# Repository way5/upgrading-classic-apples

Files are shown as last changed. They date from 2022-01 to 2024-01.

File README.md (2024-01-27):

# <p align="center">Upgrading Classic Apples</p>

<p align="center">
Apple Logo
</p>

<h2>Table of Contents</h2>

+ [**- Macintosh Classic**](#--macintosh-classic)
+ [**- Macintosh Plus**](#--macintosh-plus)
+ [**- Zero Track Finder for SONY MP-F75W**](#--zero-track-finder-for-sony-mp-f75w)
+ [**- Apple II / II+**](#--apple-ii--ii)
  + [**+ DATANEKTICS Keyboard: key switch shackle**](#-datanektics-keyboard-key-switch-shackle)
  + [**+ Rear Insert for Apple II**](#-rear-insert-for-apple-ii)
+ [**- Apple Keyboard (M7803)**](#--apple-keyboard-m7803)
+ [**- Apple Silentype (A2M0032)**](#--apple-silentype-a2m0032)

<br>

<table cellpadding="0" cellspacing="0" width="100%">
<tr><td>

ATTENTION

</td><td>

**<u>DISCHARGE</u> the CRT before doing any service inside of your Mac.**

</td></tr>

<tr><td>



</td><td>

**Please refer to [issues](https://github.com/way5/mac-classic-pram-battery-bay/issues) :beetle: if you have a suggestion or found an error.**&nbsp;&nbsp;&nbsp;&nbsp;&nbsp;&nbsp;&nbsp;&nbsp;&nbsp;&nbsp;&nbsp;&nbsp;&nbsp;&nbsp;&nbsp;&nbsp;&nbsp;&nbsp;&nbsp;&nbsp;&nbsp;&nbsp;&nbsp;&nbsp;&nbsp;&nbsp;&nbsp;&nbsp;&nbsp;&nbsp;&nbsp;&nbsp;&nbsp;&nbsp;&nbsp;&nbsp;&nbsp;&nbsp;&nbsp;&nbsp;&nbsp;&nbsp;&nbsp;&nbsp;&nbsp;&nbsp;&nbsp;&nbsp;&nbsp;&nbsp;&nbsp;&nbsp;&nbsp;

</td></tr>
</table>

## **- [Macintosh Classic](./models/macintosh%20classic/)**

<table cellpadding="0" cellspacing="0" width="100%">
<tr><td width="160px">
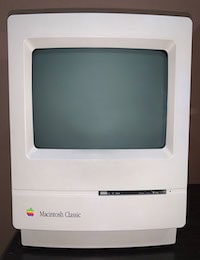
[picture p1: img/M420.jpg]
Macintosh Classic

</td><td>
The PRAM battery compartment sits between the logic board and the case (see photos).<br>Batteries will serve longer if you choose to use it from the same manufaturer and maintain them well charged. In my experience 3.2-3.9V total is enougn for proper timekeeping.
</td></tr></table>

<br>

**BOM:**

1. PRAM battery compartment
   - Wire <= AWG22 ~ 0.1 m
   - Single flat contact plates for AA, AAA batteries - 6 pcs.

---

**PLEASE NOTE**: \
Before to install the battery compartment with the batteries inside it should be electrically isolated from the logic board, otherwise the permanent damage of electrical circuits might occur. For that purpose I'm using thin (~0.5mm) transparent film, wrapping it over the battery compartment and securing it on the connector (see photos).

---

**<h3>+ Photos</h3>**

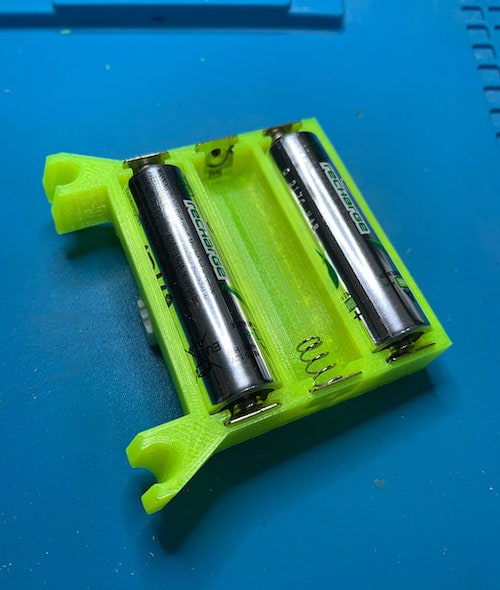
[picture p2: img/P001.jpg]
top view
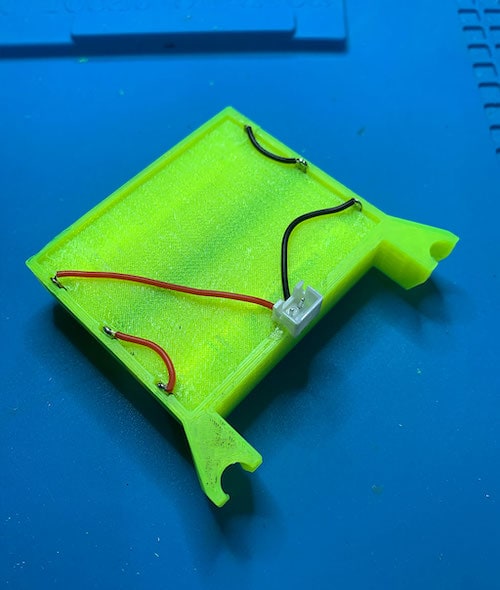
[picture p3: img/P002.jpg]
bottom view
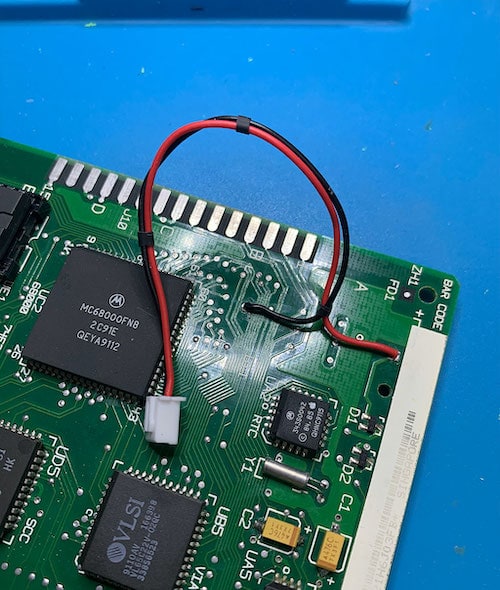
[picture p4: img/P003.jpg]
logic board
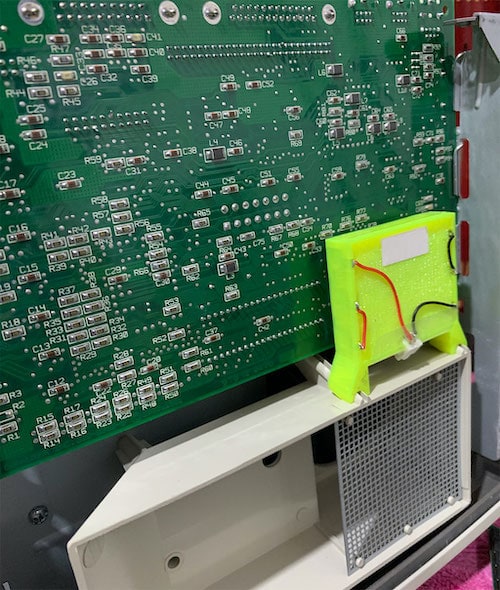
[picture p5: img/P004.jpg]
installation
|  |  |  |  |
|:---:|:---:|:---:|:---:|

</br>

## **- [Macintosh Plus](./models/macintosh%20plus/)**

<table cellpadding="0" cellspacing="0" width="100%">
<tr><td width="160px">
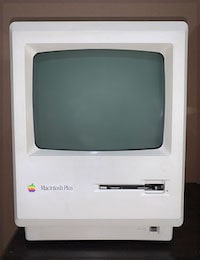
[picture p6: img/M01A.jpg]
Macintosh Plus

</td><td>

PRAM Battery. <br>The battery case is pretty much as for previous model with the only difference, it attaches directly to standard battery holder of Mac. Despite it designed to use 4.5V battery, in my experience 3.5 ± 0.4V is enough.  <br>Cooling Fan (Noninvasive method). <br>Mac Plus was designed to be cooled passively via natural convective flow through the ventilation grates all over its housing. Usually this is not enough, so it gets noticeably hot, so the cooling fan may be installed in order to make Mac's life longer.

</td></tr></table>

<br>

**BOM:**

1. PRAM battery compartment
   - Wire <= AWG22 ~ 0.1m
   - Single flat contact plates for AA, AAA batteries - 6 pcs.
   - Copper foil ~ 30mm2

**<h3>+ Photos</h3>**

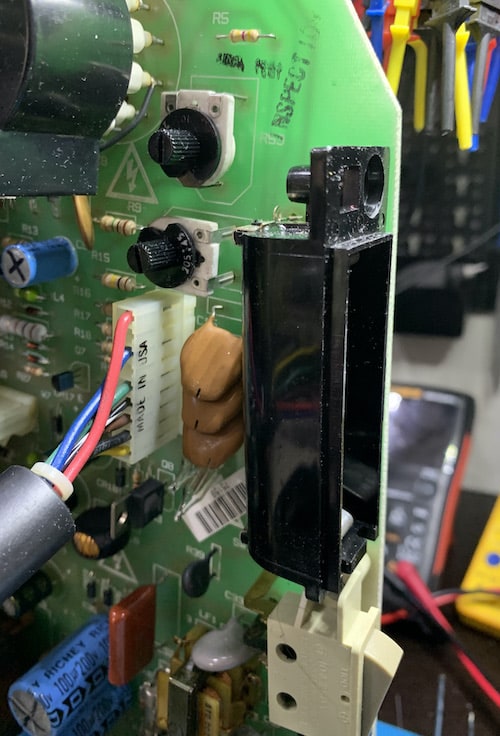
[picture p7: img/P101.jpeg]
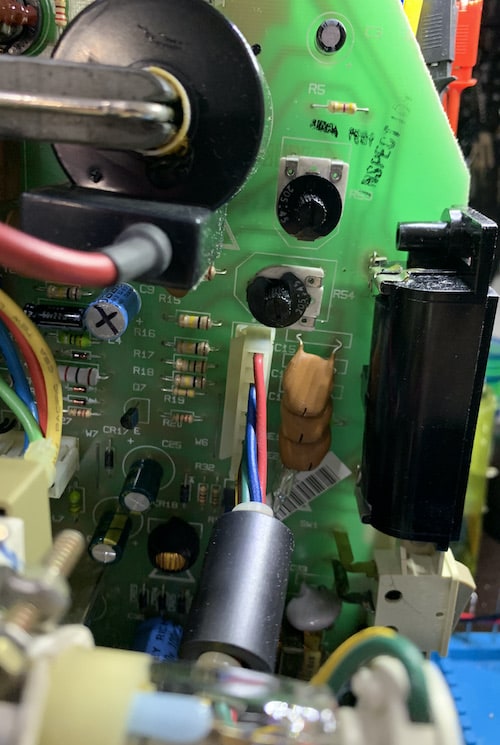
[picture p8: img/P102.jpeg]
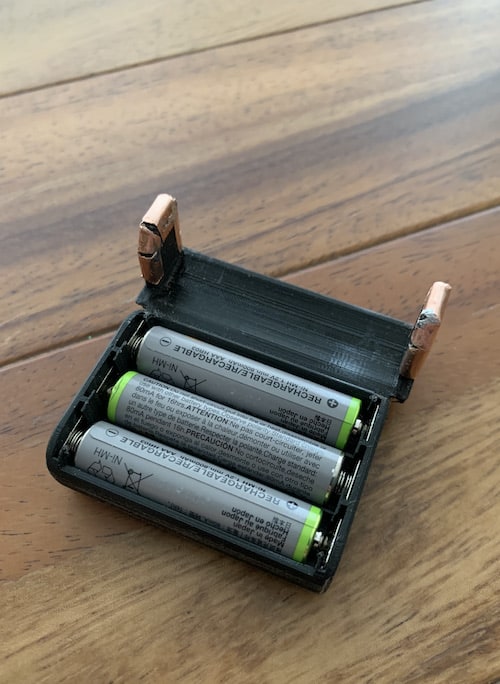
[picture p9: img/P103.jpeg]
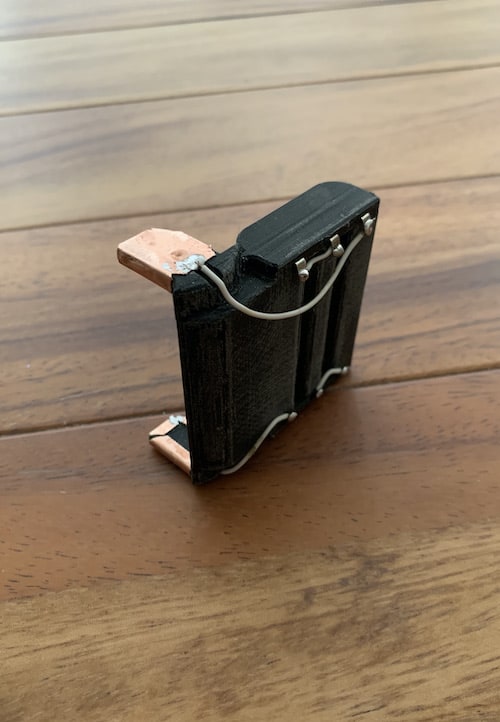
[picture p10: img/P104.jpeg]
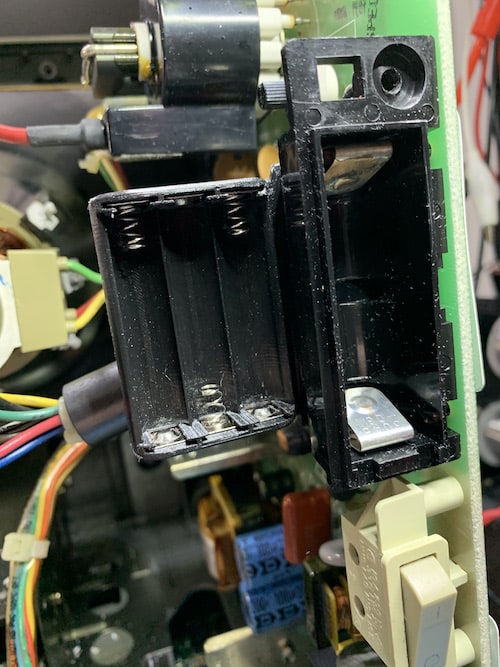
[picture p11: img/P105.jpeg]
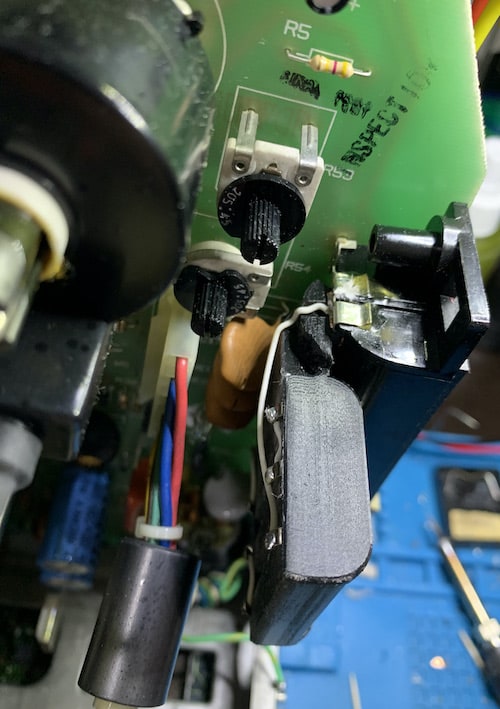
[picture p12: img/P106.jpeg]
|  |  |  |  |  |  |
|:---:|:---:|:---:|:---:|:---:|:---:|

<br>

2. Cooling fan
   - Bolts M3 - 4 pcs.
   - Thru Threaded Inserts M3 - 4 pcs.
   - Washer Head Screws (for plastic) - 2 pcs.
   - Wire <= AWG22 - 0.5m
   - Diode rectifier (ex. 1N4007) - 1 pcs.
   - Double sided tape.
<br>Optional:
   - Copper foil ~ 30mm2
   - Resistor (~50Ω) - 1 pcs.

<br>

---

**PLEASE NOTE:**: \
I'd not recommend you to use the fancy connector that you can see on the photos below, unless you know what you are doing. It requires that its both parts to be perfectly aligned, so when you close the housing it makes secure contact at all times.<br>
A much secure solution is to use any of the following connectors:

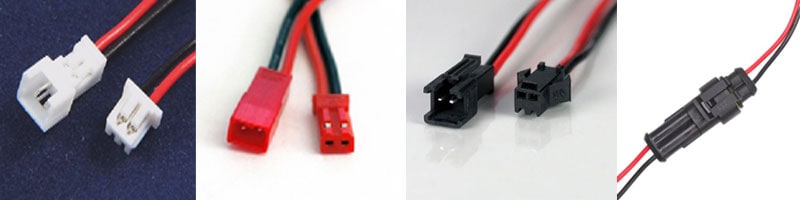
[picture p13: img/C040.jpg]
connectors


---

**<h3>+ Photos</h3>**

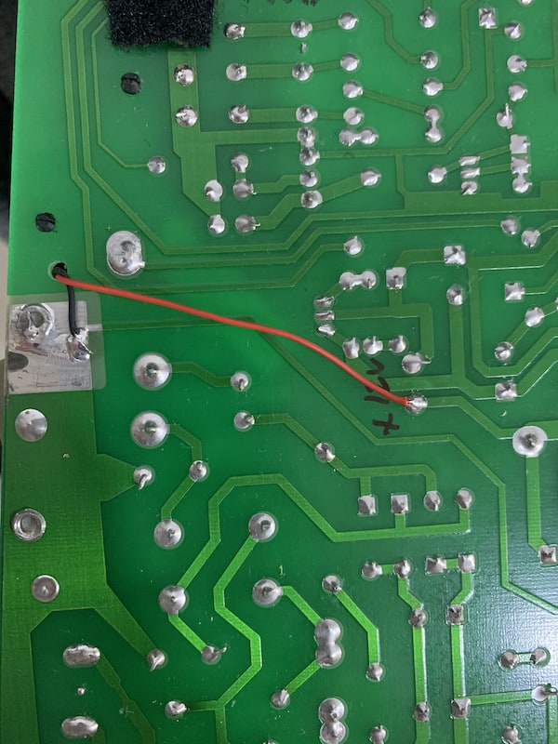
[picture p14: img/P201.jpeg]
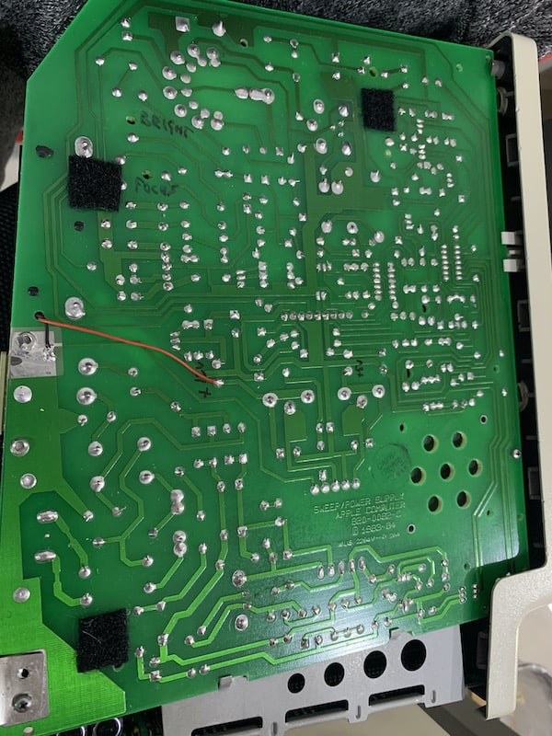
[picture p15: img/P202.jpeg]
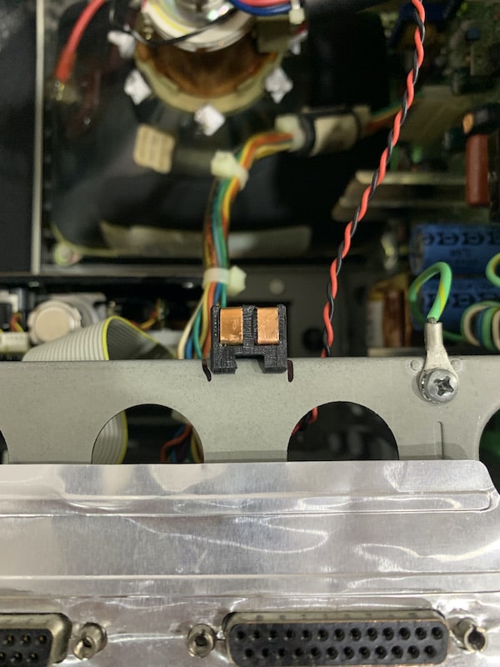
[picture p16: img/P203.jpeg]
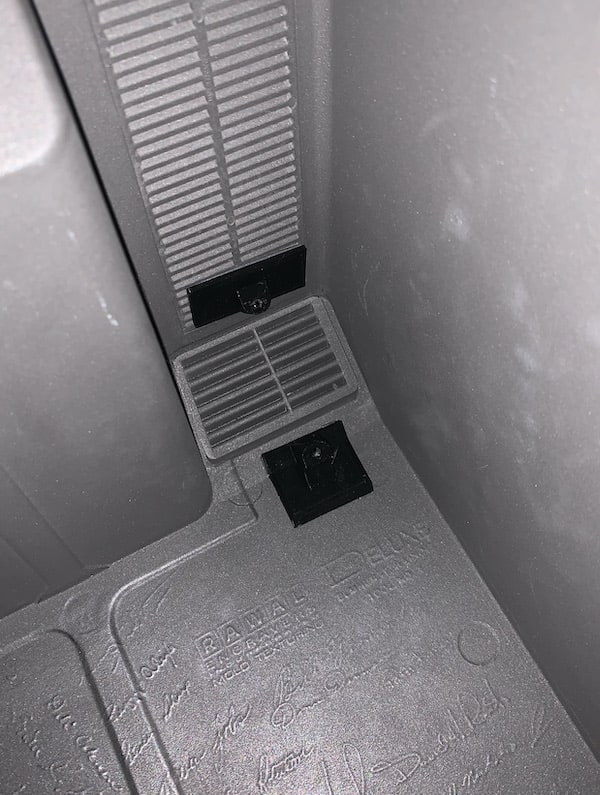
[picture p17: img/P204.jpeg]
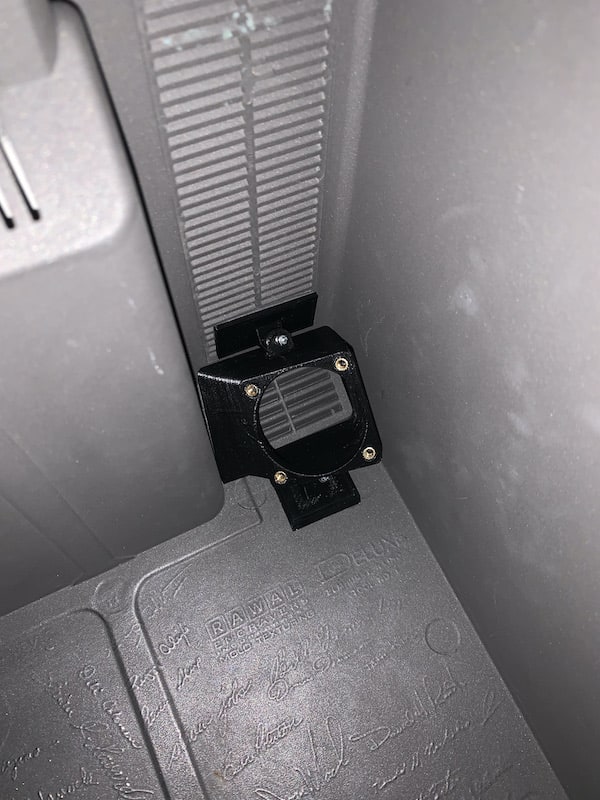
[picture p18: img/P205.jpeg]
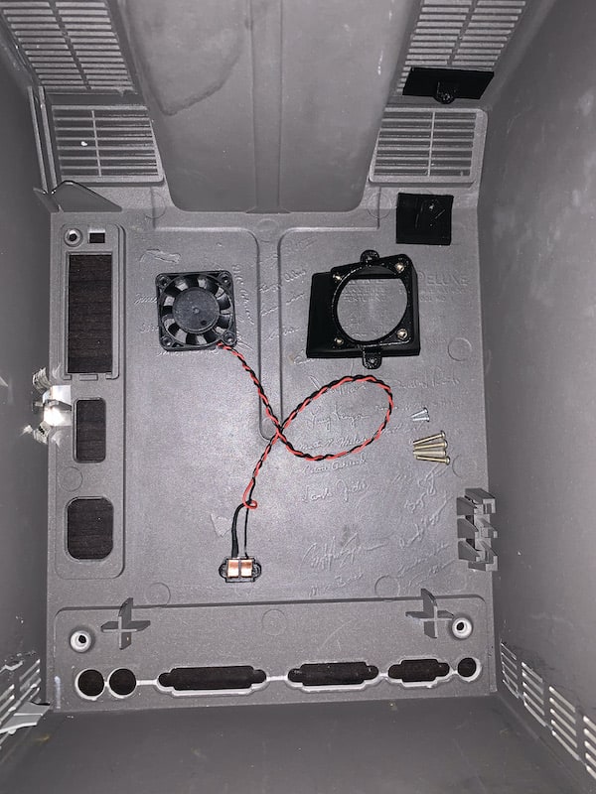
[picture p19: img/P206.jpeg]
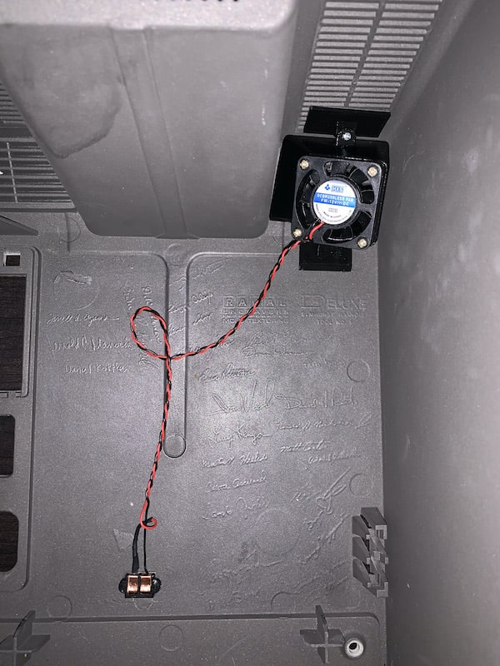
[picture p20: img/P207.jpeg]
|  |  |  |  |  |  |  |
|:---:|:---:|:---:|:---:|:---:|:---:|:---:|

<br>

## **- [Zero Track Finder for SONY MP-F75W](./models/sony%20MP-F75W/)**

<table cellpadding="0" cellspacing="0" width="100%">
<tr><td width="160px">
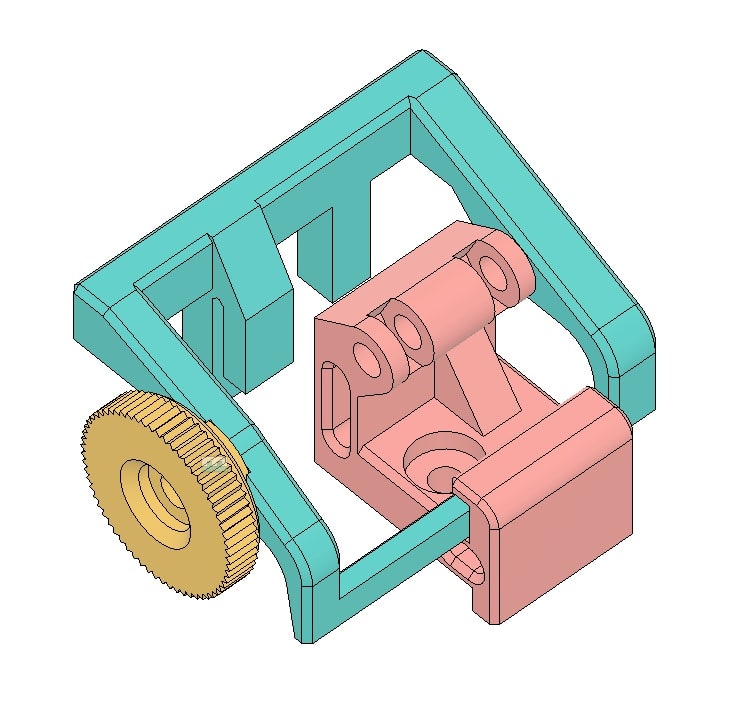
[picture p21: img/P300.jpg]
Zero Track finder for SONY-F75W

</td><td>

**<p>DO NOT USE if your drive operates properly</p>**
A simple tool which may help you to adjust zero track sensor on SONY-F75W-XX floppy drives. Place it over the sensor and secure the assembly. Loosen the sensor screw and slowly adjust the knob, insert the disk. If zero track has been found the floppy will start reading properly, if not repeat adjustment and insert the disk again. Once you finished, secure the sensor on its place and take off Zero Finder assembly.

</td></tr></table>

**<h3>+ Photos</h3>**

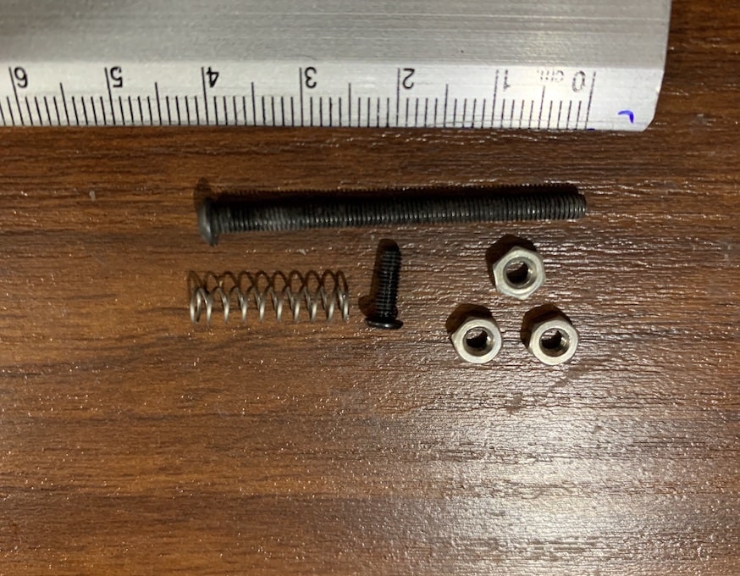
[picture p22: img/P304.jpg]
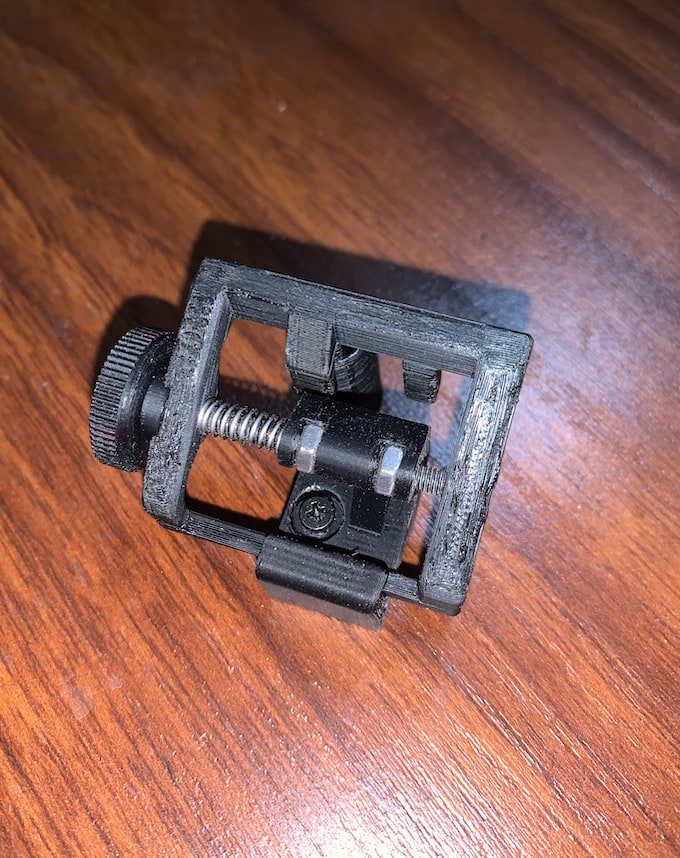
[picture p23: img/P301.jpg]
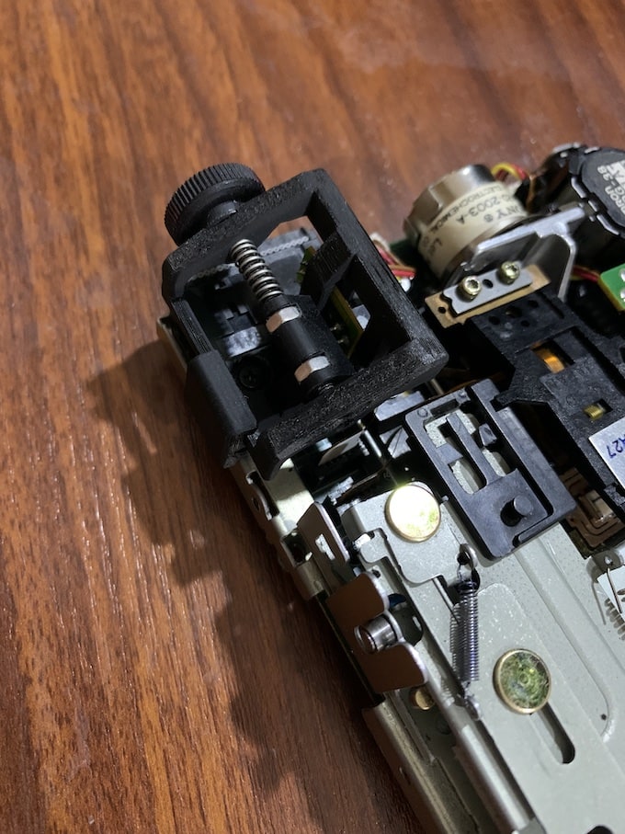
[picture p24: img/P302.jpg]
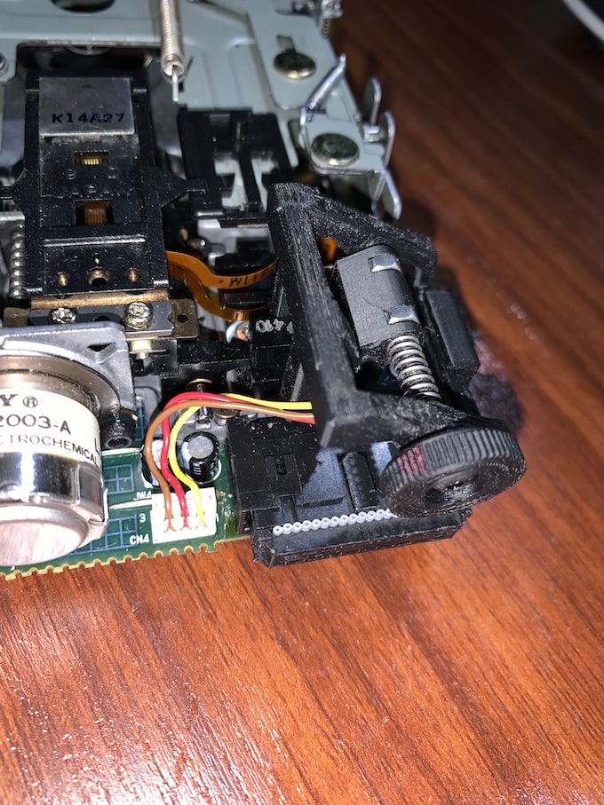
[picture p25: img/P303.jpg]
|  |  |  |  |
|:---:|:---:|:---:|:---:|
<br>

## **- [Apple II / II+](./models/apple%20II/)**

### **+ [DATANEKTICS Keyboard: key switch shackle](./models/apple%20II/datanectics%20keyboard%20switch%20shackle_v7.f3d)**

<table cellpadding="0" cellspacing="0" width="100%">
<tr><td width="160px">

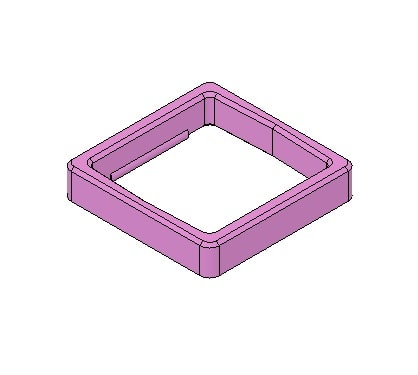
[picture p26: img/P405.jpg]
Apple II Datanekticts Keyboard repair


</td><td>

There are a multiple ways to repair Apple II's Datanektiks keyboard. My decision was to crack open all malfunctioning key switches to give them a proper maintainment. When the key is back to work, clean and lubricated, you may glue the both halves of the key mechanism together as it was before or to leave the opportunity to painlessly open if it will fail again. The key swith shackle securely holds the both parts of the mechanism together and may be easily removed by whatever reason you need to open the switch in future. 
<p><u>Hint:</u> Be very careful when opening the key switch with the cutter knife, do not apply too much force. Open it from the opposite side to the contact pins.</p>

</td></tr></table>

**<h3>+ Photos</h3>**

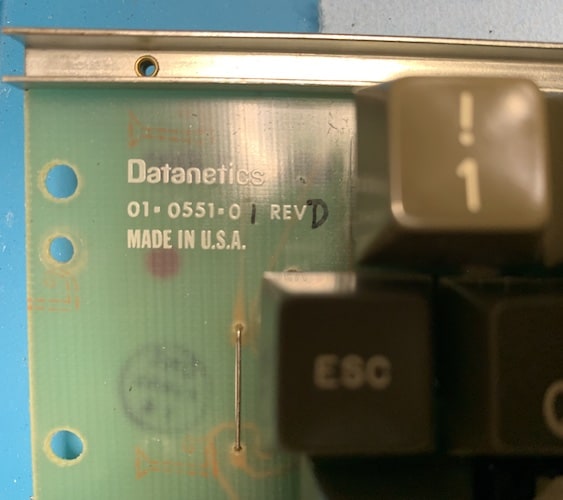
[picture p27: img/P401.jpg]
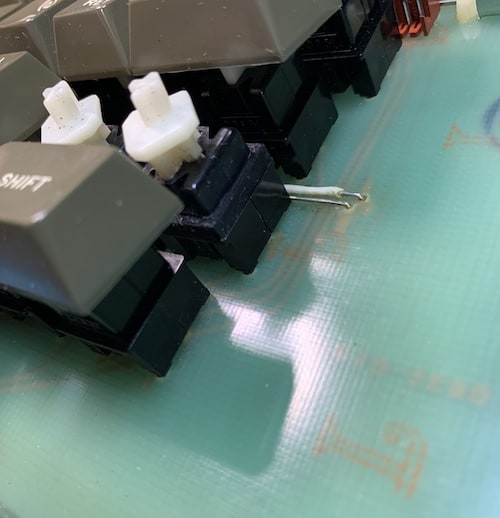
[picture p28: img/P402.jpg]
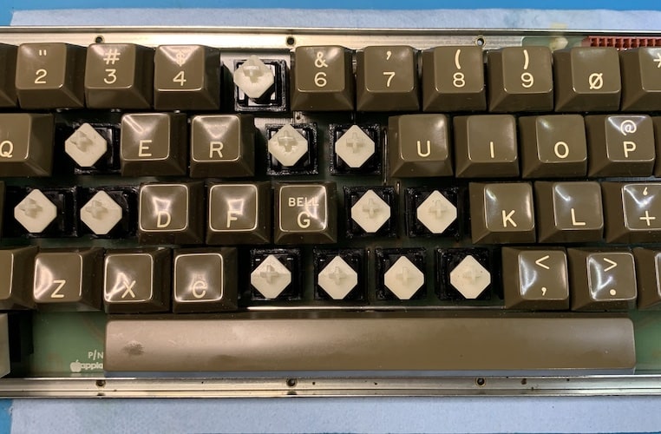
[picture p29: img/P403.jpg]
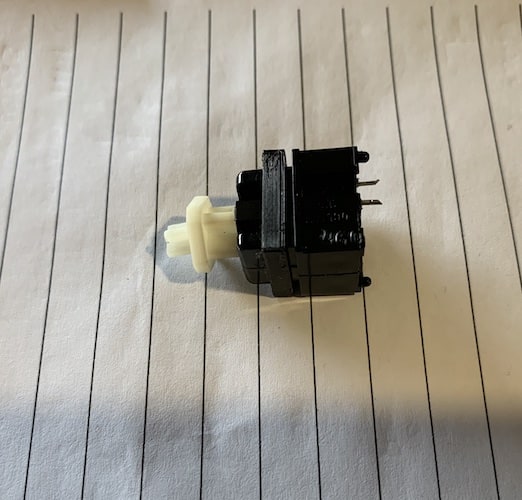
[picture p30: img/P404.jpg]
|  |  |  |  |
|:---:|:---:|:---:|:---:|

### **+ [Rear Insert for Apple II](./models/apple%20II/rear_insert_v16.f3d)**
<table cellpadding="0" cellspacing="0" width="100%">
<tr><td width="160px">
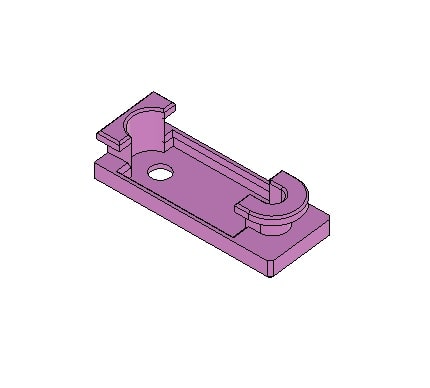
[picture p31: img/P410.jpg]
Apple II Plus

</td><td>

Just a simple insert, originally designed for Apple II+ in order to allow some cable management on the rear side of the housing.

</td></tr></table>

<br>

## **- [Apple Keyboard (M7803)](./models/imac%20g4/m7809_keyboard_key_shaft.stl)**

<table cellpadding="0" cellspacing="0" width="100%">
<tr><td width="160px">
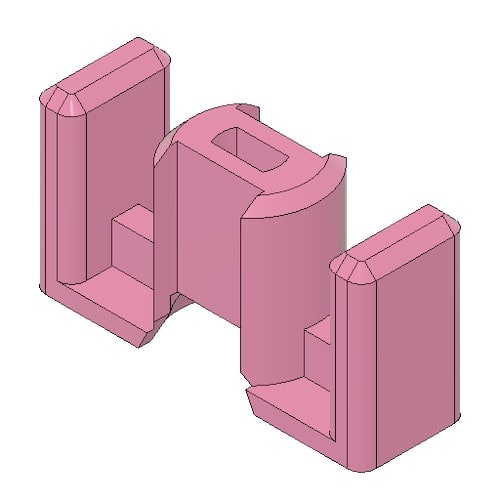
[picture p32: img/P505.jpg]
iMac G4 keyboard M7803

</td><td>

The Apple keyboards are rarely reliable particularly an old ones. Let's give a chance to one of the most fragile devices by modifying the switching mechanism, adding custom key shaft instead of an unreliable side clips.

</td></tr></table>

**<h3>+ Photos</h3>**

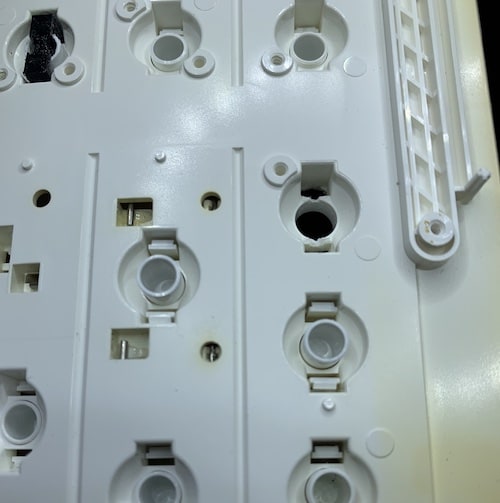
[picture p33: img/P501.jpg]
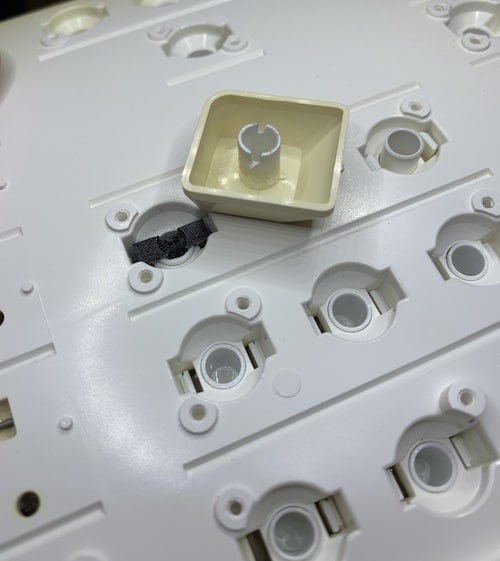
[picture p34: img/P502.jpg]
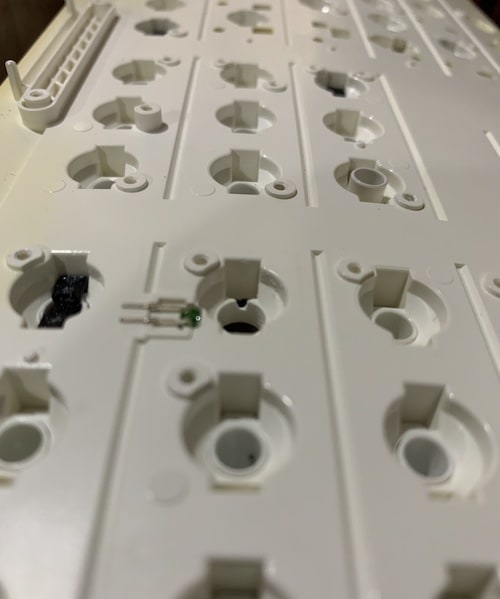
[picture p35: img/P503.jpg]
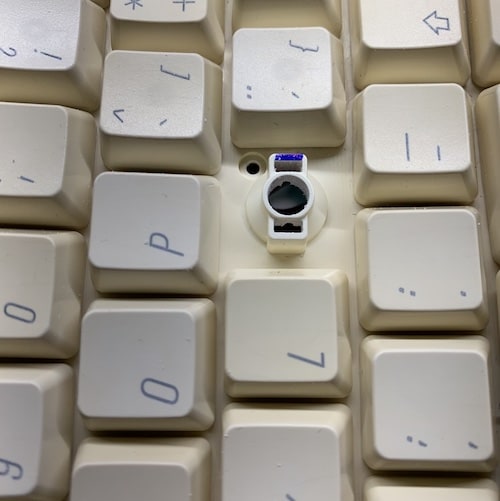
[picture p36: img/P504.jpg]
|  |  |  |  |
|:---:|:---:|:---:|:---:|

## **- [Apple Silentype (A2M0032)](./models/apple%20silentype/)**

<table cellpadding="0" cellspacing="0" width="100%">
<tr><td width="160px">
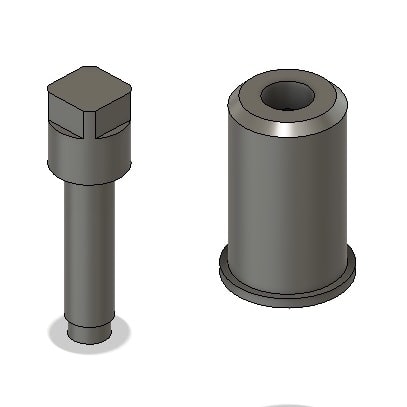
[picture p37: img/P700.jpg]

</td><td>

The Apple Silentype had two plastic inserts on both sides of the paper roll. Sometimes one or both of these are lost. To fully assemble the insert you'd also need a spiral spring of corresponding diameters and the starlock stopper ring (outer d = ~7mm).

</td></tr>
<tr><td width="160px">
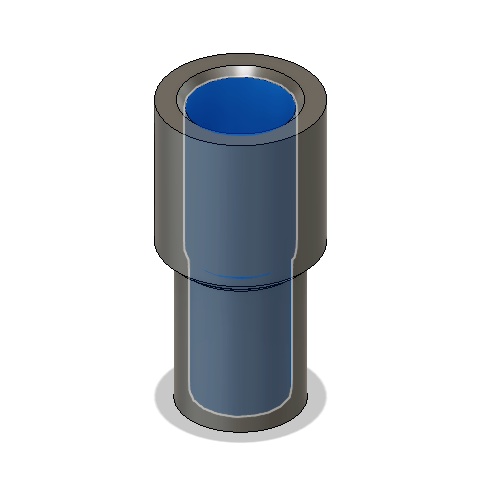
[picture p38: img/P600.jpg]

</td><td>

The main shaft of paper feeding mechanism is connected to the stepper motor through the plastic bushing which becomes brittle over time. You probably already faced the need to replace it or in the near future would do. This [printable model](./models/apple%20silentype/bushing.stl) may resolve the issue.

</td></tr></table>

**<h3>+ Photos</h3>**

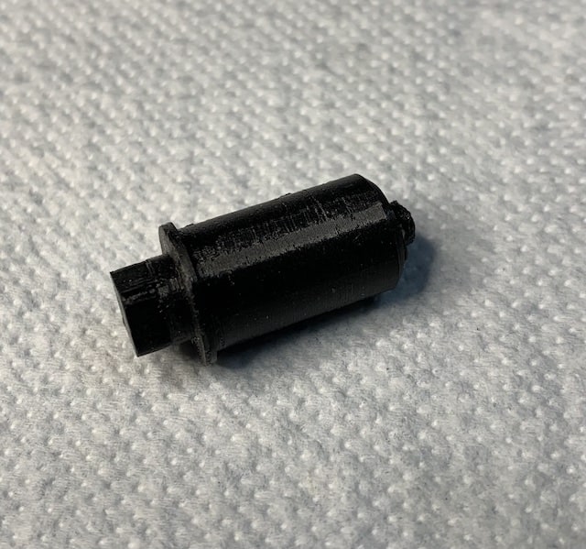
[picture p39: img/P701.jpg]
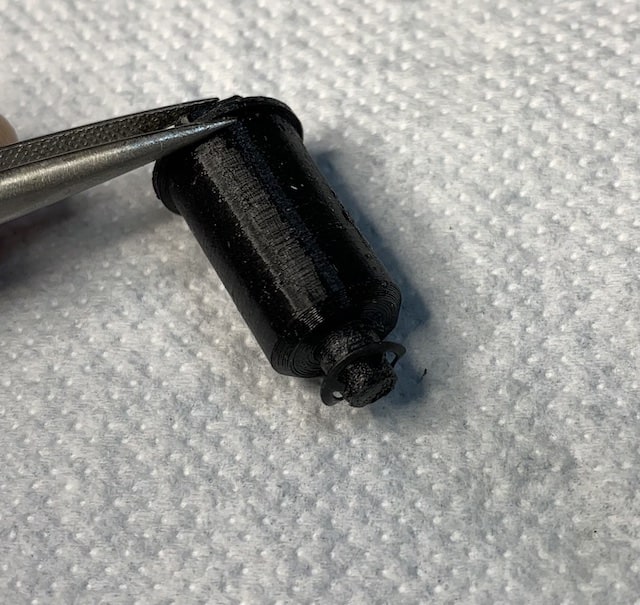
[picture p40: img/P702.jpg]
|  |  |  |
|:---:|:---:|:---:|

<br><hr>

<sup><sup>Apple logo is used in accordance with paragraph #4 of the article [Authorized Use of Apple Trademarks](https://www.apple.com/legal/intellectual-property/guidelinesfor3rdparties.html) </sup></sup>

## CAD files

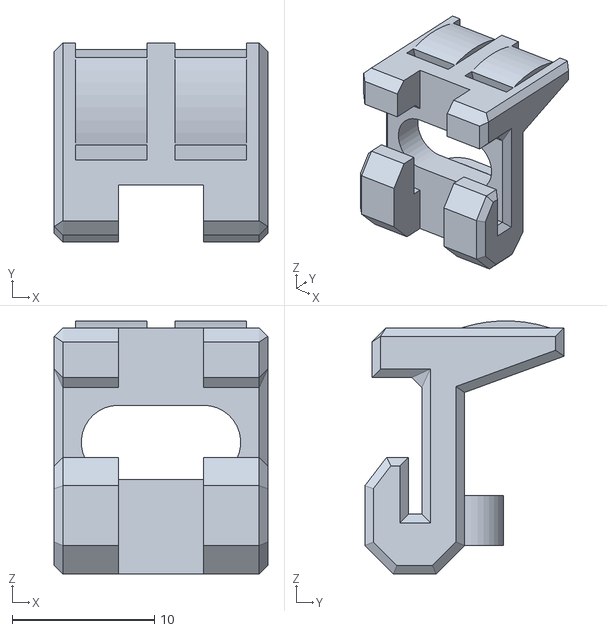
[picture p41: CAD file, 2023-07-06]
models/macintosh plus/cooling fan/connector/plus_fan_connector_passy.stl
15.0 x 14.0 x 17.8

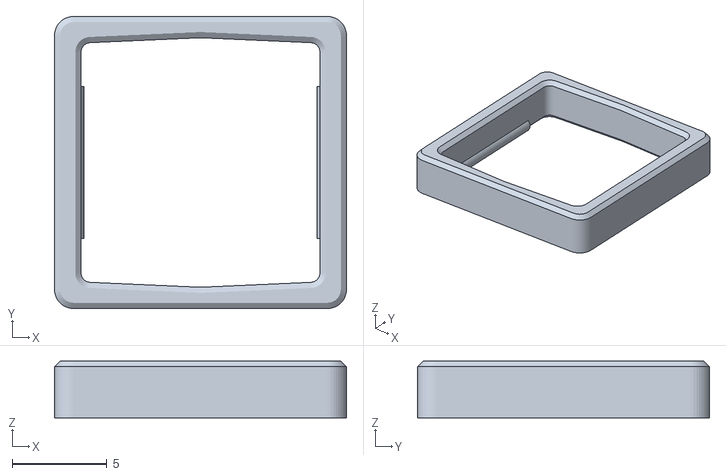
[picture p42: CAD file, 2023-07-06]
models/apple II/datanectics keyboard switch shackle.stl
15.4 x 15.4 x 3.00

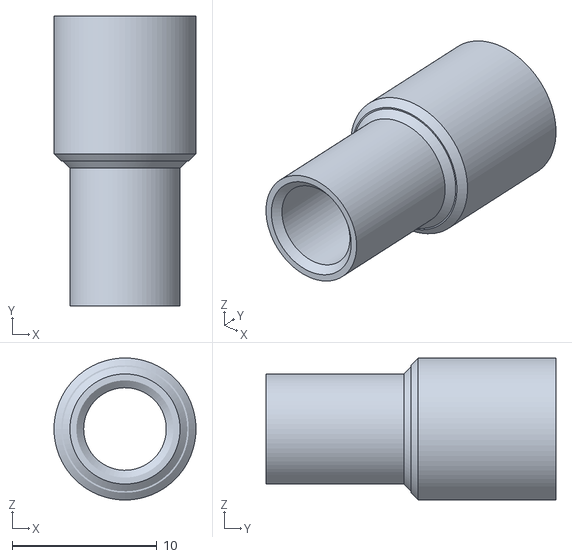
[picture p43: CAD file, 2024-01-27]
models/apple silentype/bushing.stl
9.80 x 20.0 x 9.80

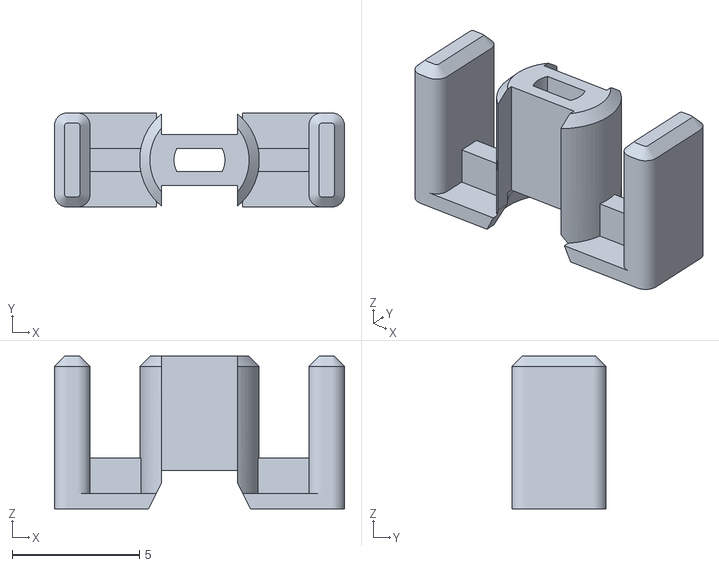
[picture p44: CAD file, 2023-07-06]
models/imac g4/m7809_keyboard_key_shaft.stl
11.4 x 3.70 x 6.00

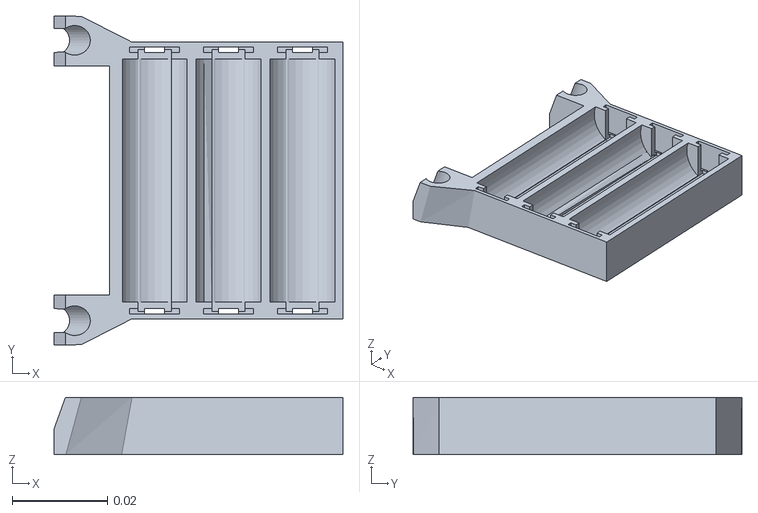
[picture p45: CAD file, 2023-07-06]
models/macintosh classic/pram_battery_compartment_2A.stl
0.0606 x 0.069 x 0.012

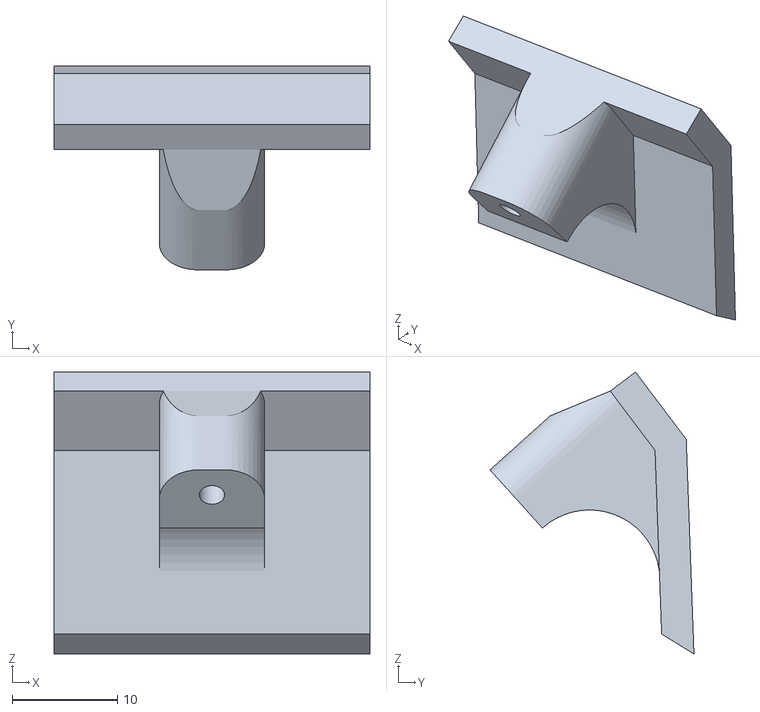
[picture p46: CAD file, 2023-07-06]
models/macintosh plus/cooling fan/plus_fan_sprtpad_btm.stl
30.0 x 19.4 x 26.8

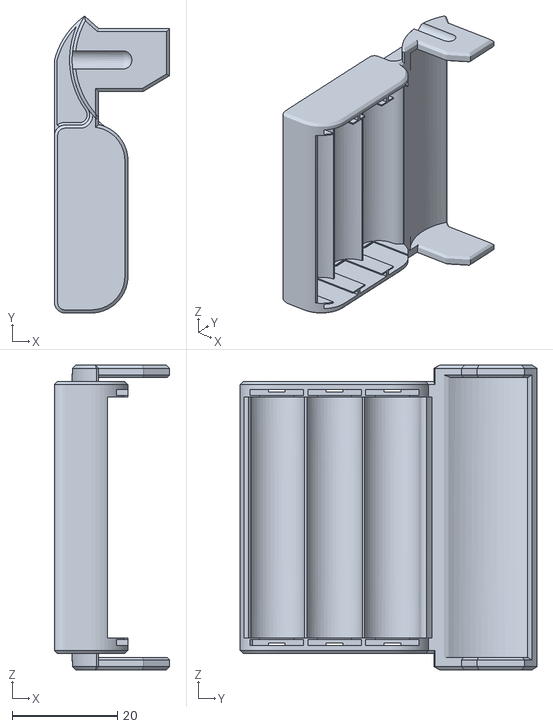
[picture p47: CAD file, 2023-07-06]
models/macintosh plus/pram_battery_compartment_3A.stl
21.9 x 56.5 x 58.0

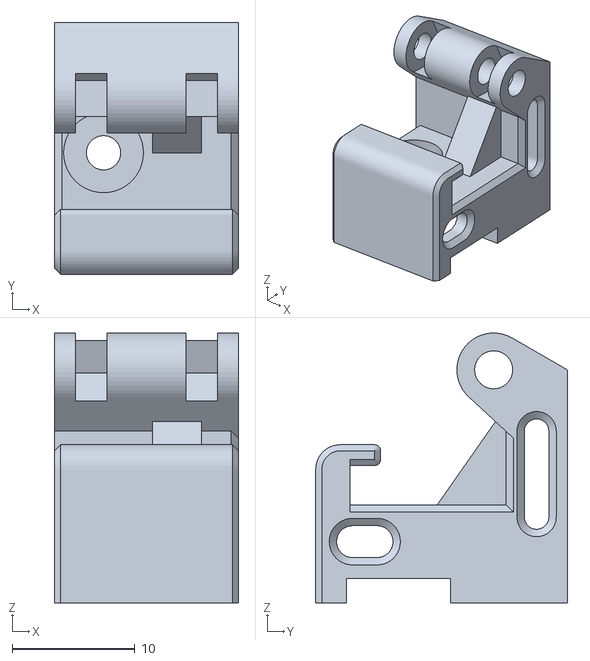
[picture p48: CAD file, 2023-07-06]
models/sony MP-F75W/base.stl
15.0 x 20.5 x 22.0

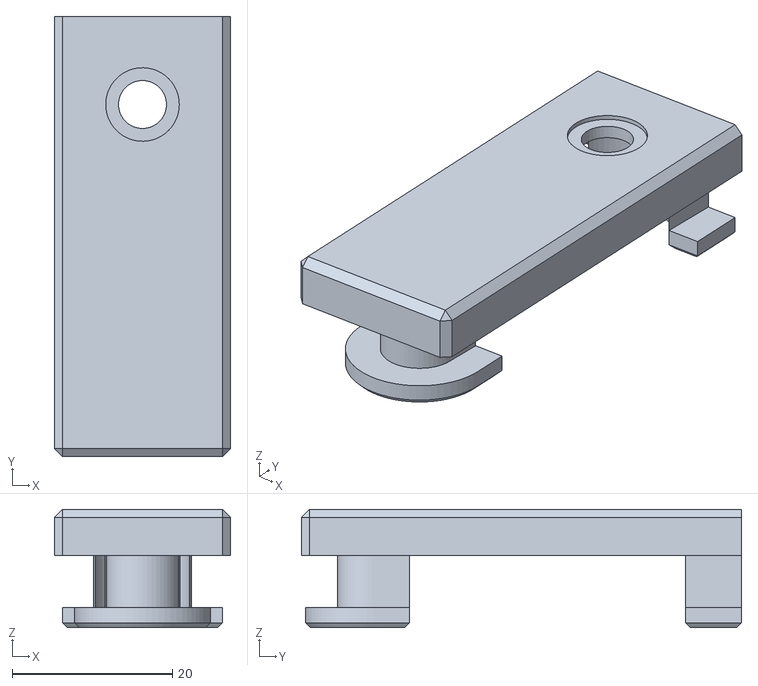
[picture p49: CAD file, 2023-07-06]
models/apple II/rear insert.stl
22.0 x 55.0 x 14.8

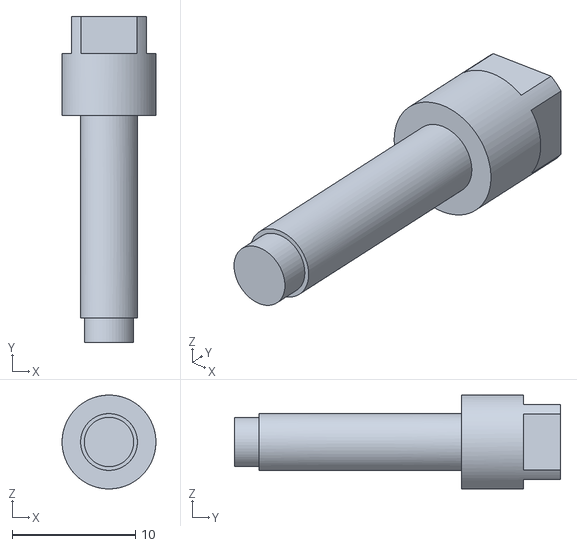
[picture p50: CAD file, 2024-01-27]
models/apple silentype/pin.stl
7.60 x 26.4 x 7.60

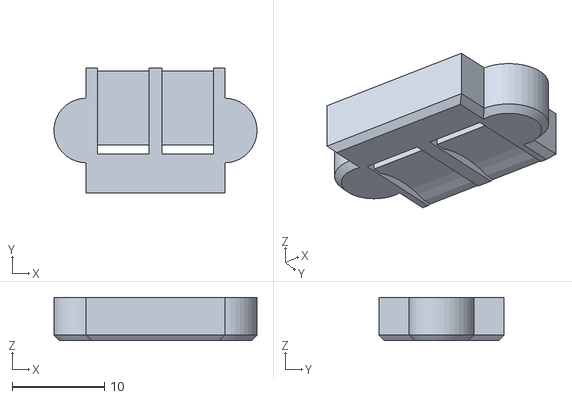
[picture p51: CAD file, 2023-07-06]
models/macintosh plus/cooling fan/connector/plus_fan_connector_pcasing.stl
22.0 x 13.5 x 4.70

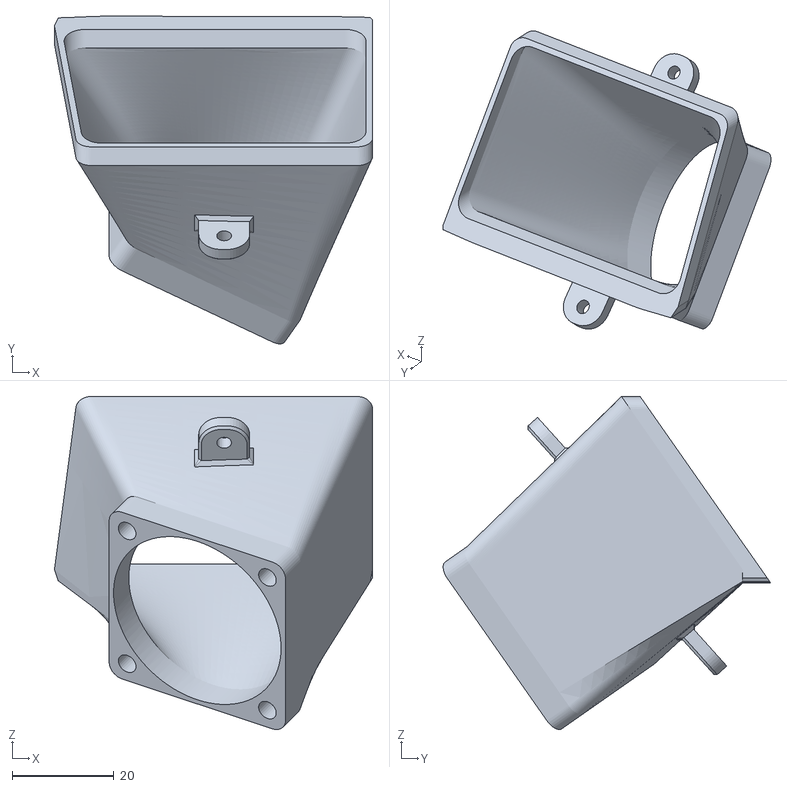
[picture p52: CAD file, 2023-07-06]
models/macintosh plus/cooling fan/plus_fan_shell.stl
62.5 x 64.4 x 65.4

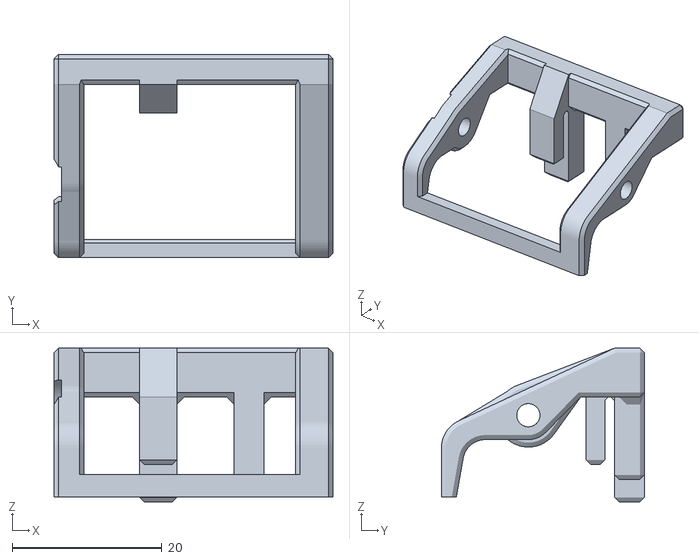
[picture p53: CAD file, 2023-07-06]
models/sony MP-F75W/linkage.stl
37.2 x 27.1 x 20.5

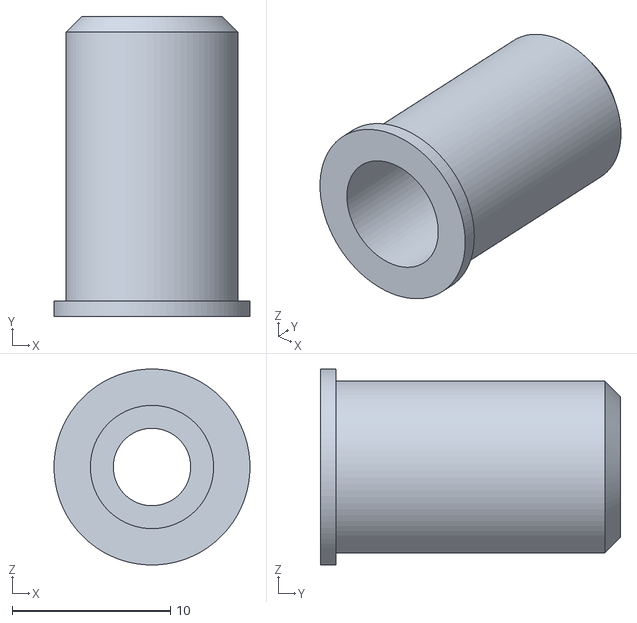
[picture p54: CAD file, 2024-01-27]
models/apple silentype/drum.stl
12.4 x 19.0 x 12.4

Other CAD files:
models/macintosh plus/cooling fan/plus_fan_sprtpad_top.stl
models/sony MP-F75W/knob.stl
models/apple II/datanectics keyboard switch shackle.obj
models/apple II/datanectics keyboard switch shackle_v7.f3d
models/apple II/rear insert.obj
models/apple II/rear_insert_v16.f3d
models/apple silentype/a2m0032_paper_roll_pin_ v7.f3d
models/apple silentype/a2m0032_shaft_bushing_v3.f3d
models/imac g4/m7809_keyboard_key_shaft.obj
models/imac g4/m7809_keyboard_key_shaft_v12.f3d
models/macintosh classic/pram_battery_compartment_2A.obj
models/macintosh plus/cooling fan/connector/plus_fan_connector_passy.obj
models/macintosh plus/cooling fan/connector/plus_fan_connector_pcasing.obj
models/macintosh plus/cooling fan/plus_fan_shell.obj
models/macintosh plus/cooling fan/plus_fan_sprtpad_btm.obj
models/macintosh plus/cooling fan/plus_fan_sprtpad_top.obj
models/macintosh plus/pram_battery_compartment_3A.obj
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

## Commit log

2022-01-02 Mac Plus battery, cooling
    [plus_fan_connector_passy.obj, plus_fan_connector_pcasing.obj, plus_fan_shell.obj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]
2022-10-30 ZTF for sony-f75w
    [base.obj, knob.obj, linkage.obj]
2023-07-06 '23 up
    [base.obj, base.stl, datanectics keyboard switch shackle.obj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]
2024-01-27 apple silentype
    [a2m0032_paper_roll_pin_ v7.f3d, a2m0032_shaft_bushing_v3.f3d, base.obj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]
